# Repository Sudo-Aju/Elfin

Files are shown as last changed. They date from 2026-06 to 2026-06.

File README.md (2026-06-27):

<div align="center">

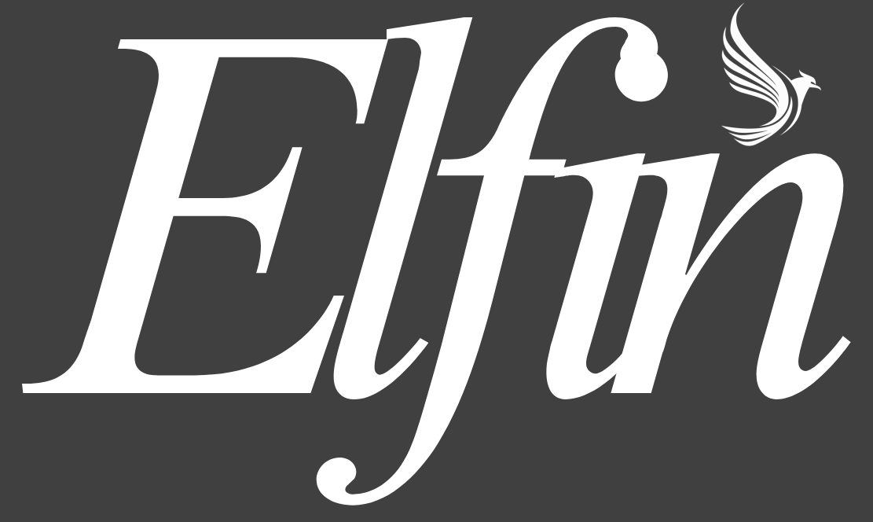
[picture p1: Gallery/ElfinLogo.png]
elfinlogo
# 

A Tiny 4 Layer ATSAMD21E18A Development Board 

<p>




</p>

### _So light that it flies._

<p align="center">
  
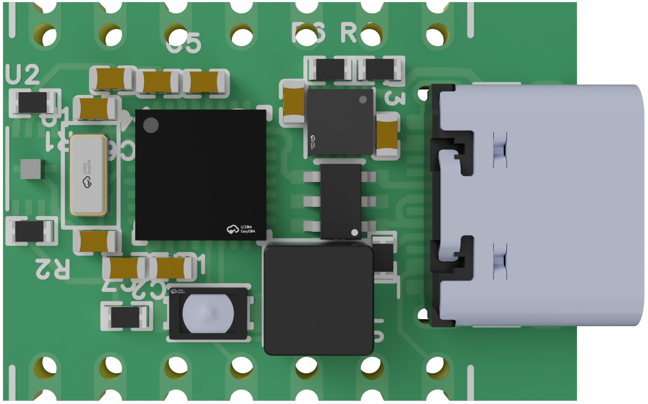
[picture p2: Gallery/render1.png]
  
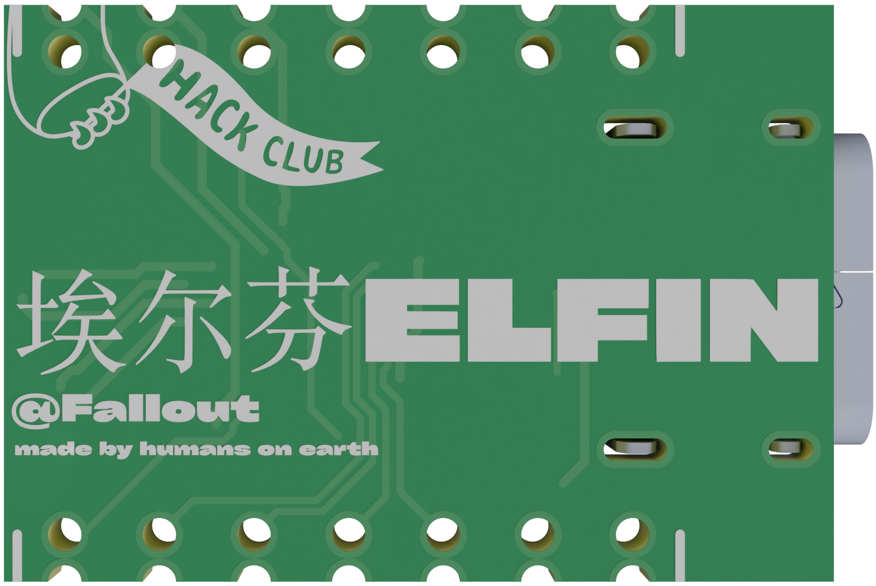
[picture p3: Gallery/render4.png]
  
  
</p>
</div>

---

# Overview

**Elfin** is an ultra-compact development board built around the **ATSAMD21E18A**, designed for embedded developers, makers, and educators who require a capable microcontroller in an exceptionally small footprint.

Measuring just **22.3 × 15.5 mm**, Elfin integrates the essential hardware required for rapid prototyping while maintaining a layout suitable for manufacturing, debugging, and long-term embedded deployment.

Key hardware includes:

- ATSAMD21E18A ARM Cortex-M0+ Microcontroller
- Native USB Type-C Connectivity
- 2 MB External SPI Flash
- 32.768 kHz RTC Crystal Oscillator
- Fully Exposed GPIO
- Optimized Four-Layer PCB

The board is intended for applications where board area is limited without compromising functionality or expandability.

---

# Gallery

<div align="center">

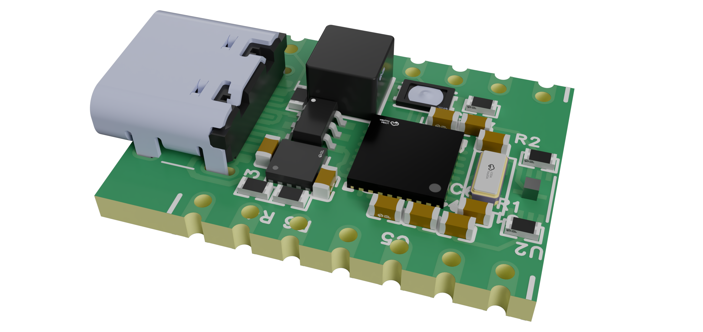
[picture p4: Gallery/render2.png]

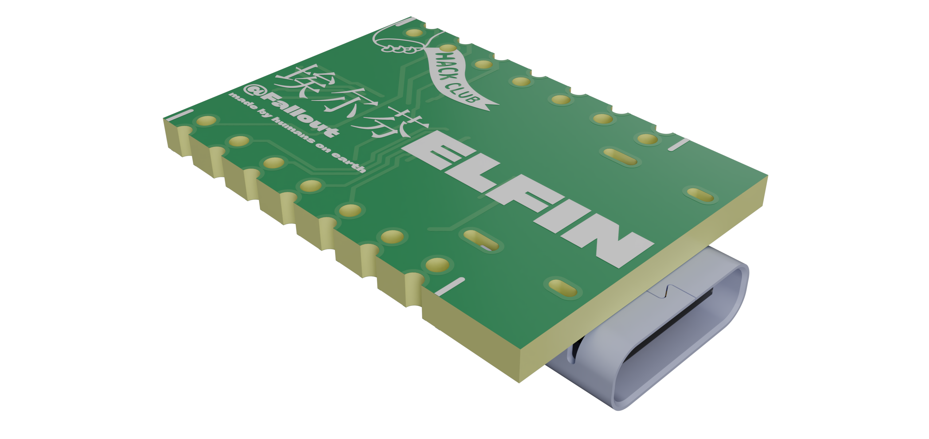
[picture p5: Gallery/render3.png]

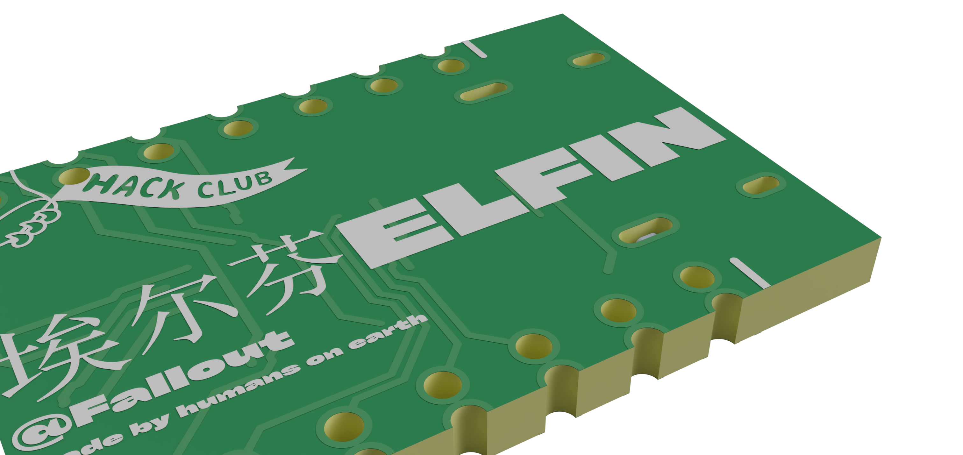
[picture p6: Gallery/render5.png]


</div>

---

# Zine

<div align="center">
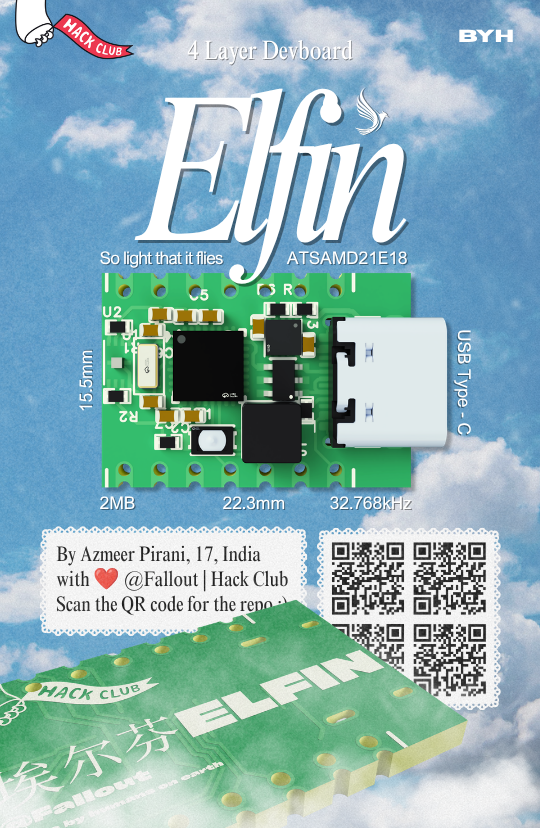
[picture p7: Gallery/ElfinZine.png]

</div>

---

# Motivation

Most development boards are designed around convenience.

Elfin was designed around minimalism.

The goal was simple:

> How small can a fully featured ATSAMD21 development board become?

The project explored compact embedded hardware design while maintaining usability, manufacutrability, and flexibility.

Inspired by:
- Tiny embedded systems
- Wearable electronics
- Open-source hardware
- Hack Club hardware projects
- Minimalist engineering

The result is a board that feels compact in size while remaining practical for real-world development. (Not the smallest tho 🤓)

---

# Features

- ATSAMD21E18A ARM Cortex-M0+ MCU
- Native USB Type-C Interface
- 2 MB External SPI Flash Memory
- Dedicated 32.768 kHz RTC Crystal
- Four-Layer High-Density PCB
- SWD Programming & Debugging
- Fully Exposed GPIO
- Breadboard Compatible Layout
- Open-Source Hardware Design
- Compact 22.3 × 15.5 mm Form Factor

---

# Hardware Stack

| Parameter | Value |
|---|---|
| MCU | ATSAMD21E18A |
| Internal Flash | 256KB |
|SRAM|32KB|
|Crystal|32.768kHz RTC Crystal|
|External Flash|2MB External SPI Flash|
|USB|USB Type-C|
|Operating Voltage|3.3V|
|PCB|4 Layer PCB (```Signal, Ground, Power, Signal```) |
|Programming|UF2 / SWD|
|Power|USB Powered|
|Dimensions|22.3mm x 15.5mm|

---

# BOM

|No.|Quantity|Comment |Designator |Footprint |Value |Manufacturer Part|Manufacturer |Supplier Part|Supplier |Link |
|---|---|---|---|---|---|---|---|---|---|---|
|1  |4 |100nF |C1,C3,C6,C7|C0402 |100nF |CL05B104KB5NNNC  |SAMSUNG(三星) |C1525 |LCSC |https://www.lcsc.com/product-detail/C1525.html |
|2  |3 |1uF |C2,C4,C5 |C0402 |1uF |CL05A105KA5NQNC  |SAMSUNG(三星) |C52923 |LCSC |https://www.lcsc.com/product-detail/C52923.html |
|3  |2 |10uF |C8,C9 |C0402 |10uF |CL05A106MP5NUNC  |SAMSUNG(三星) |C15525 |LCSC |https://www.lcsc.com/product-detail/C15525.html |
|4  |1 |USBLC6-2SC6 |D1 |SOT-23-6_L2.9-W1.6-P0.95-LS2.8-BR |USBLC6-2SC6 |USBLC6-2SC6 |ST(意法半导体) |C7519 |LCSC |https://www.lcsc.com/product-detail/C7519.html |
|5  |2 |castellated_holes_1x7 |H1,H2 |Carl Bugeja's Library.IntLib:castellated holes |castellated holes |N/A |N/A |N/A |Custom PCB Feature|N/A |
|6  |1 |USB_C_Receptacle_USB2.0_16P|J1 |Connector_USB:USB_C_Receptacle_HCTL_HC-TYPE-C-16P-01A|USB_C_Receptacle_USB2.0_16P|HC-TYPE-C-16P-01A|HCTL |C2894897 |LCSC |https://www.lcsc.com/product-detail/C2894897.html |
|7  |1 |2.2uH |L1 |IND-SMD_L4.0-W4.0_XAL4030-332MEC |2.2uH |SMNR4020-2.2UH |SXN(顺翔诺) |C135262 |LCSC |https://www.lcsc.com/product-detail/C135262.html |
|8  |3 |10K |R1,R2,R3 |R0402 |10K |RC0402FR-0710KL  |YAGEO |C25744 |LCSC |https://www.lcsc.com/product-detail/C25744.html |
|9  |2 |5.1K |R4,R5 |R0402 |5.1K |RC0402FR-075K1L  |YAGEO |C25905 |LCSC |https://www.lcsc.com/product-detail/C25905.html |
|10 |1 |36.5K |R6 |R0402 |36.5K |RC0402FR-0736K5L |YAGEO |C25793 |LCSC |https://www.lcsc.com/product-detail/C25793.html |
|11 |1 |EVPAWCD40 |SW1 |KEY-SMD_L3.0-W2.0-LS3.5 |EVPAWCD40 |EVPAWCD40 |PANASONIC(松下)  |C2858606 |LCSC |https://www.lcsc.com/product-detail/C2858606.html |
|12 |1 |ATSAMD21E18A-MUT |U1 |QFN-32_L5.0-W5.0-P0.50-TL-EP3.6 |ATSAMD21E18A-MUT |ATSAMD21E18A-MUT |MICROCHIP(美国微芯)|C2052801 |LCSC |https://www.lcsc.com/product-detail/C2052801.html |
|13 |1 |W25Q16JVUXIQ |U2 |USON-8_L3.0-W2.0-P0.50-BL-EP |W25Q16JVUXIQ |W25Q16JVUXIQ |Winbond(华邦) |C2843335 |LCSC |https://www.lcsc.com/product-detail/C2843335.html |
|14 |1 |TPS63900DSKR |U3 |WSON-10_L2.5-W2.5-W0.50-TL-EP |TPS63900DSKR |TPS63900DSKR |TI(德州仪器) |C1518762 |LCSC |https://www.lcsc.com/product-detail/C1518762.html |
|15 |1 |32.768KHz |X1 |OSC-SMD_L3.2-W1.5 |32.768KHz |ABS07-32.768KHZ-T|Abracon |C9900004736  |LCSC |https://www.lcsc.com/product-detail/Crystals_ABRACON-ABS07-32-768KHZ-T_C9002.html|

---

# PCB Design

The PCB layout was designed around maximizing routing efficiency within an extremely constrained footprint while preserving signal integrity, manufacturability, and accessibility.

A four-layer stack-up was selected to improve routing density, provide continuous ground and power planes, and simplify high-speed USB and power distribution.

Key design considerations included:

- High-density component placement
- Optimized USB routing
- Continuous ground return paths
- Efficient power distribution
- SWD debugging accessibility
- Compact mechanical footprint
  
## PCB
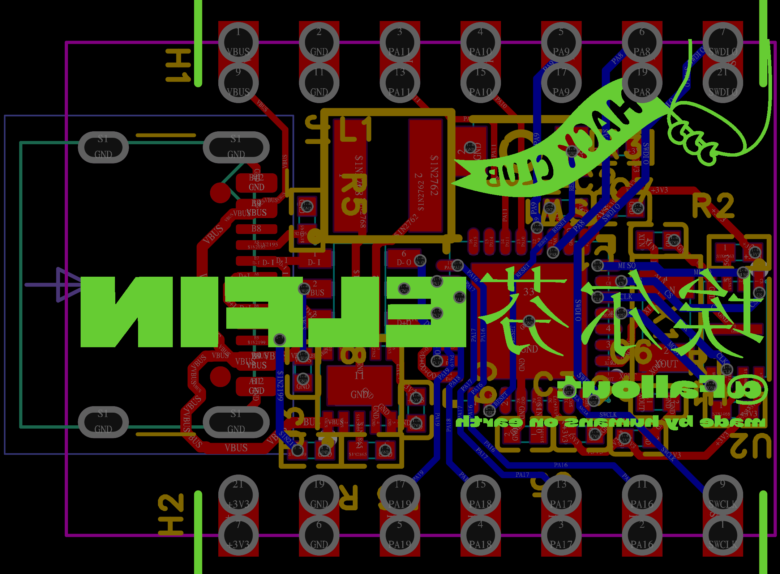
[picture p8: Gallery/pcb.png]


## Schematic
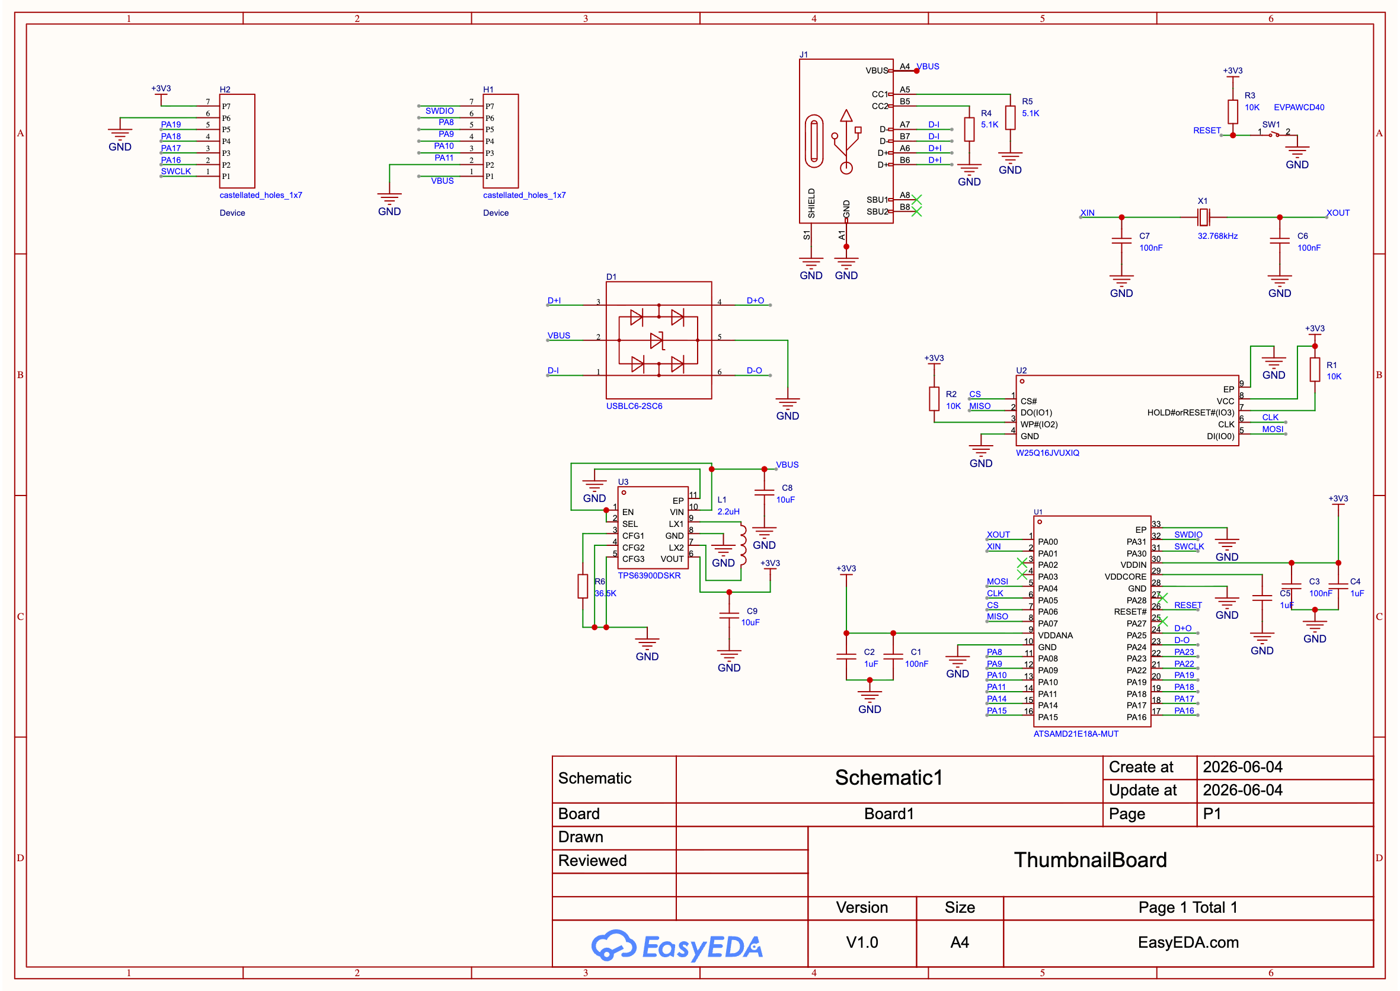
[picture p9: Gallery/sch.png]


---

# Assemble Guide

## 1. Order the PCB

Navigate to:

```bash
./PCB/ElfinGerber.zip
```

Upload the Gerber files to your preferred PCB manufacturer.

---

## 2. Order Components

All required components can be found in:

```bash
./PCB/ElfinBOM.csv
```

---

## 3. Solder the Components

Recommended assembly should follow a low-profile to high-profile sequence to simplify alignment and reduce rework.

Suggested order:

1. Passive components
2. Crystal oscillator
3. SPI Flash
4. Buck-Boost Converter
5. ATSAMD21E18A
6. USB Type-C Connector

---

## 4. Inspect the Board

Before powering:
- Check for shorts
- Verify USB connections
- Inspect power rails
- Confirm crystal orientation

---

## 5. Program the Bootloader

Using an SWD programmer:
- Connect SWDIO
- Connect SWCLk
- Connect GND
- Flash teh UF2 bootloader

---

## 6. Upload the Firmware

Once the bootloader is installed:
- Connect USB Type-C
- Enter bootloader mode
- Drag and drop the firmware

---

# Applications

Elfin is perfect for:

- Wearables
- USB Devices
- Sensor Nodes
- Robotics
- IoT Projects
- Custom Controllers
- Educational Projects
- Compact Embedded Systems

---

# Repository Structure

```bash
Elfin/
├── PCB/
├── CAD/
├── Firmware/
├── Assets/
└── README.md
```

---

# Current Status

- [X] Initial Concept
- [X] Schematic Design
- [X] PCB Design
- [X] Hardware Validation
- [ ] Firmware Bring-up
- [ ] Functional Testing
- [ ] Community Evaluation 

---

# Contributing

Contributions, suggestions, and feedback are welcome.

If you'd like to improve Elfin:

```bash
git clone https://github.com/Sudo-Aju/Elfin.git
cd Elfin
```

1. Create a feature branch
2. Make your changes
3. Commit your work
4. Open a pull request

---

# Creator

### Azmeer Pirani

Built with ❤️ for:
- Embedded Systems
- PCB Design
- Open Source Hardware
- Tiny Things

---

# License

This project is licensed under the MIT License.

---

<div align="center">

## ELFIN

### _So light that it flies_

</div>

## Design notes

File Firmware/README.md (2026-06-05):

# Firmware

MCU: ATSAMD21E18A

Recommended software support:

- ArduinoCore-samd
- Adafruit SAMD Core
- UF2 Bootloader

The board has not yet been physically tested.

Users should flash a compatible SAMD21 bootloader using SWD.

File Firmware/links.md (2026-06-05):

Arduino Core:
https://github.com/arduino/ArduinoCore-samd

Adafruit Core:
https://github.com/adafruit/ArduinoCore-samd

UF2 Bootloader:
https://github.com/microsoft/uf2-samdx1

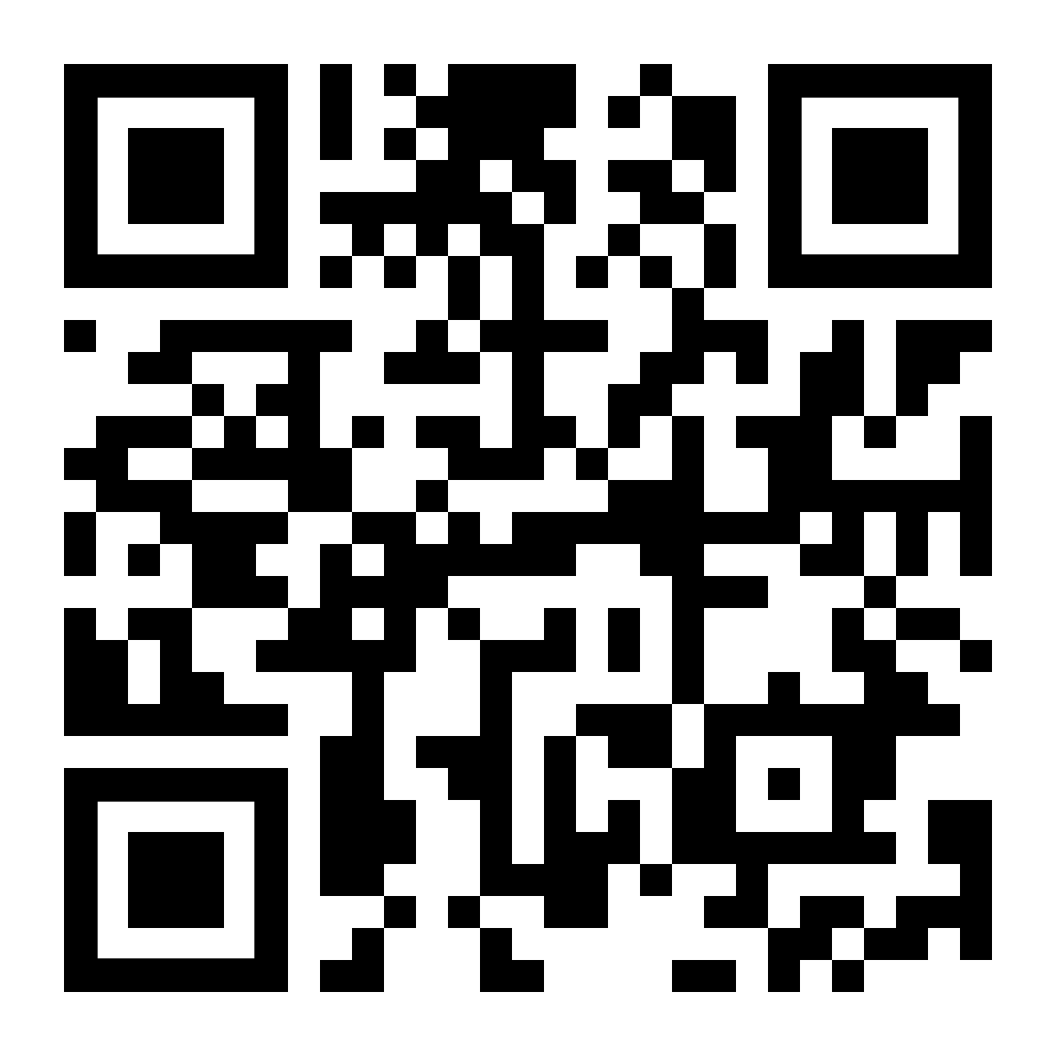
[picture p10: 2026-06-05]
Gallery/ElfieQR.png

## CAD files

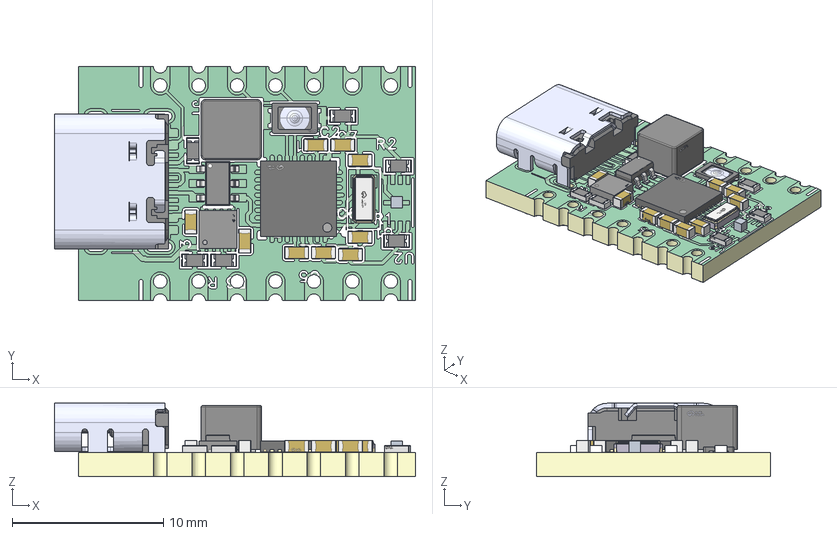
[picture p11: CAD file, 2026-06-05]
CAD.step
23.9 x 15.5 x 4.86 mm
Board~j9jJ
TopCopper~j9jJ x 80
BottomCopper~j9jJ x 26
TopSilkscreen~j9jJ x 58
BottomSilkscreen~j9jJ x 50
TopFpcStiffener~j9jJ
BottomFpcStiffener~j9jJ
USON-8_L3.0-W2.0-P0.50-BL-EP~USON-8_L2-W3-H0.6X0.5P~j9jJ
SOT-23-6_L2.9-W1.6-P0.95-LS2.8-BR~SOT-23-6_L2.9-W1.6-P0.95-LS2.8-BR-3~j5ts
R0402~R0603~BG7i x 6
WSON-10_L2.5-W2.5-W0.50-TL-EP~WSON-10_L2.5-W2.5-W0.50-TL-EP~kQRH
Connector_USB:USB_C_Receptacle_HCTL_HC-TYPE-C-16P-01A~HX-TYPE-C-16P~hBoW
IND-SMD_L4.0-W4.0_XAL4030-332MEC~IND-SMD_L4.0-W4.0_XAL4030-332MEC~J43V
QFN-32_L5.0-W5.0-P0.50-TL-EP3.6~QFN-32_L5.0-W5.0-H0.8-P0.50-BL-EP3.7~rEGs
OSC-SMD_L3.2-W1.5~OSC-SMD_L3.2-W1.5-H0.8~2cVf
C0402~C0603_L1.6-W0.8-H0.8~dSHy x 9
KEY-SMD_L3.0-W2.0-LS3.5~KEY-SMD_2P-L3.0-W2.0-H0.5-LS3.5~qPcl

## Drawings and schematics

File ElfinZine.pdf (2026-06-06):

### 4 Layer Devboard

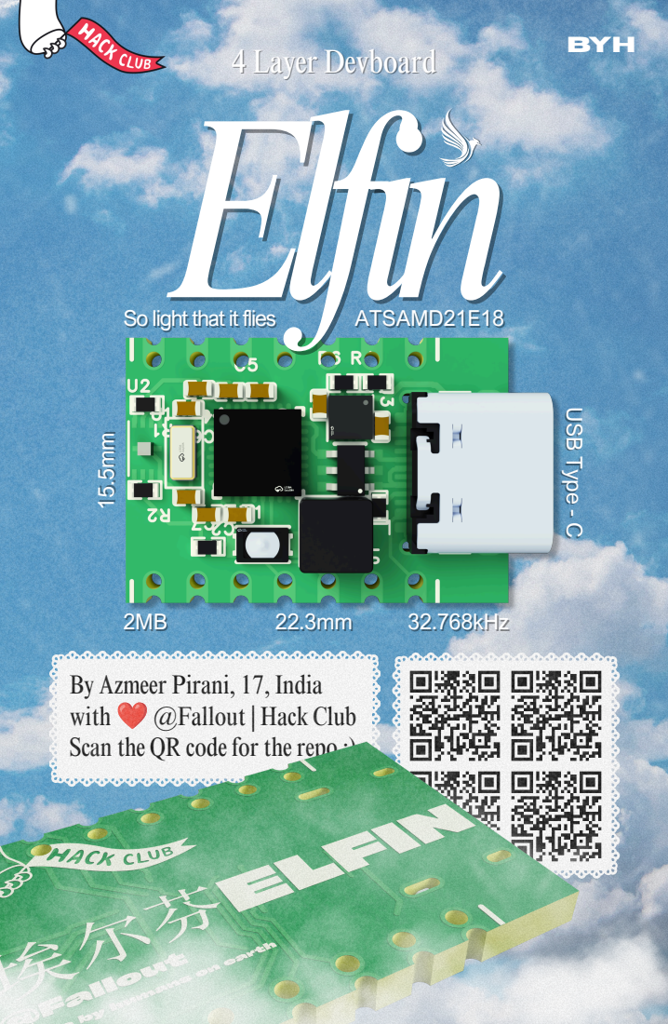
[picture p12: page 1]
32.768kHz; ATSAMD21E18; BYH

So ligEht that it flies lfin

By Azmeer Pirani, 17, India
with❤️@Fallout | Hack Club Scan the QR code for the repo :)

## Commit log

2026-06-05 added logo to readme
    [ElfinBOM.csv]
2026-06-05 Edited BOM file and moved it to PCB folder, edited readme bom, adn changed width of logo
    [ElfinBOM.csv]
2026-06-05 added a guide on how to flash the bootloader and firmware, as the board is not physically tested
2026-06-09 updated bom links
    [ElfinBOM.csv]
